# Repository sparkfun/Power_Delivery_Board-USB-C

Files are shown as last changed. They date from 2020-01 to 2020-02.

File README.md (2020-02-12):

SparkFun Power Delivery Board - USB-C
========================================

SparkFun Power Delivery Board - USB-C

[*SparkFun Power Delivery Board - USB-C (15801)*](https://www.sparkfun.com/products/15801)

<Basic description of the part.>

Repository Contents
-------------------

* **/Hardware** - Eagle design files (.brd, .sch)

Documentation
--------------
* **[Hookup Guide](https://learn.sparkfun.com/tutorials/power-delivery-board---usb-c-qwiic-hookup-guide)** - Basic hookup guide for the Power Delivery Board - USB-C.
* **[Arduino Library](https://github.com/sparkfun/SparkFun_STUSB4500_Arduino_Library)** - Arduino Library for use with the Power Delivery Board.
* **[SparkFun Fritzing repo](https://github.com/sparkfun/Fritzing_Parts)** - Fritzing diagrams for SparkFun products.

License Information
-------------------

This product is _**open source**_! 

Please review the LICENSE.md file for license information. 

If you have any questions or concerns on licensing, please contact technical support on our [SparkFun forums](https://forum.sparkfun.com/viewforum.php?f=152).

Distributed as-is; no warranty is given.

- Your friends at SparkFun.

_<COLLABORATION CREDIT>_

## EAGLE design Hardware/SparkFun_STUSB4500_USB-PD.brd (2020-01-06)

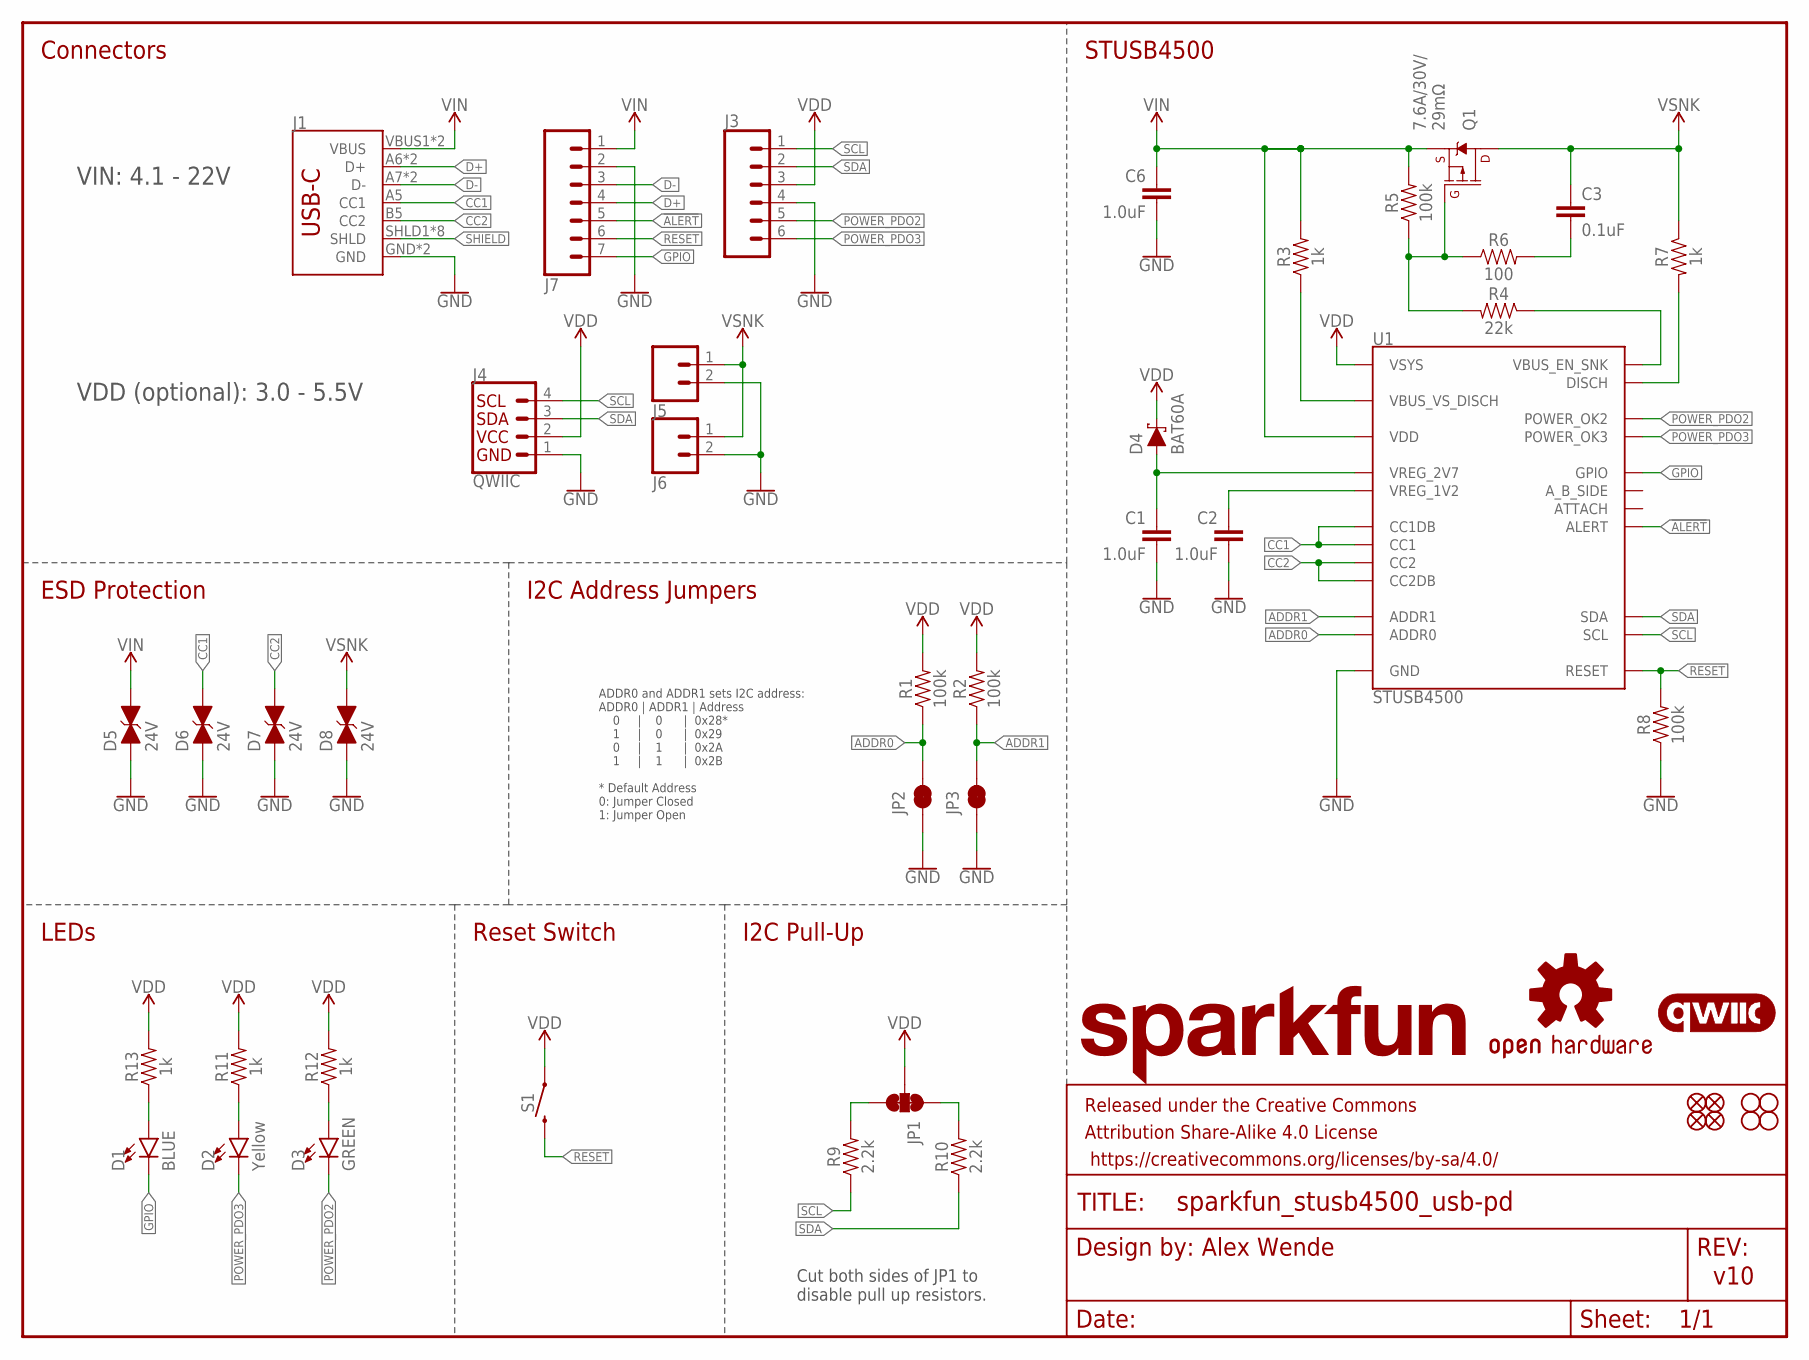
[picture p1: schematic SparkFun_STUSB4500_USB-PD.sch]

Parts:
C1, C2, C6: 1.0uF; 0603
C3: 0.1uF; 0603
D1: BLUE; LED-0603
D2: Yellow; LED-0603
D3: GREEN; LED-0603
D4: BAT60A; SOD-323
D5, D6, D7, D8: 24V; 0603
FD1, FD2, FD3, FD4: FIDUCIALUFIDUCIAL; FIDUCIAL-MICRO
FRAME1: FRAME-LETTER; CREATIVE_COMMONS
H1, H2, H3, H4: STAND-OFF
J1: USB_C2-LAYER; USB-C-16P
J3: CONN_06NO_SILK_NO_POP; 1X06_NO_SILK
J4: QWIIC; JST04_1MM_RA
J5: CONN_023.5MM; SCREWTERMINAL-3.5MM-2
J6: CONN_021X02_NO_SILK; 1X02_NO_SILK
J7: CONN_07NO_SILK; 1X07_NO_SILK
JP1: JUMPER-SMT_3_2-NC_TRACE_NO-SILK; SMT-JUMPER_3_2-NC_TRACE_NO-SILK
JP2, JP3: JUMPER-SMT_2_NC_TRACE_NO-SILK; SMT-JUMPER_2_NC_TRACE_NO-SILK
LOGO1: OSHW-LOGOS; OSHW-LOGO-S
LOGO2: SFE_LOGO_NAME.1_INCH; SFE_LOGO_NAME_.1
LOGO3: QWIIC_LOGO_5MM; QWIIC_5MM
Q1: 9A/30V/15mΩ; 8-POWERVDFN-3X3
R1, R2, R5, R8: 100k; 0603
R3, R7, R11, R12, R13: 1k; 0603
R4: 22k; 0603
R6: 100; 0603
R9, R10: 2.2k; 0603
S1: MOMENTARY-SWITCH-SPST-SMD-4.6X2.8MM; TACTILE_SWITCH_SMD_4.6X2.8MM
U1: STUSB4500; QFN-24

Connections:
1.2V: C2.1, U1.P$21 (VREG_1V2)
2.7V: C1.1, D4.A, U1.P$23 (VREG_2V7)
!ALERT: J7.5, U1.P$19 (ALERT)
ADDR0: JP2.2, R1.1, U1.P$12 (ADDR0)
ADDR1: JP3.2, R2.1, U1.P$13 (ADDR1)
CC1: D6.2 (C), J1.A5 (CC1), U1.P$1 (CC1DB), U1.P$2 (CC1)
CC2: D7.2 (C), J1.B5 (CC2), U1.P$4 (CC2), U1.P$5 (CC2DB)
D+: J1.A6 (D+), J1.B6 (D+), J7.4
D-: J1.A7 (D-), J1.B7 (D-), J7.3
DISCH: R7.2, U1.P$9 (DISCH)
EN_SNK: R4.1, U1.P$16 (VBUS_EN_SNK)
GND: C1.2, C2.2, C6.2, D5.1 (A), D6.1 (A), D7.1 (A), D8.1 (A), J1.GND, J1.GND2 (GND), J3.4, J4.1, J5.2, J6.2, J7.2, JP2.1, JP3.1, R8.1, U1.P$10 (GND), U1.P$25 (GND)
GPIO: D1.C, J7.7, U1.P$15 (GPIO)
unnamed: D2.A, R11.1
unnamed: D3.A, R12.1
unnamed: JP1.3, R9.2
unnamed: JP1.1, R10.2
unnamed: Q1.4 (G), R4.2, R5.1, R6.1
unnamed: C3.2, R6.2
unnamed: D1.A, R13.1
POWER_PDO2: D3.C, J3.5, U1.P$20 (POWER_OK2)
POWER_PDO3: D2.C, J3.6, U1.P$14 (POWER_OK3)
RESET: J7.6, R8.2, S1.3 (2), S1.4 (2), U1.P$6 (RESET)
SCL: J3.1, J4.4, R9.1, U1.P$7 (SCL)
SDA: J3.2, J4.3, R10.1, U1.P$8 (SDA)
SHIELD: J1.SHLD1 (SHLD), J1.SHLD2 (SHLD), J1.SHLD3 (SHLD), J1.SHLD4 (SHLD), J1.SHLD5 (SHLD), J1.SHLD6 (SHLD), J1.SHLD7 (SHLD), J1.SHLD8 (SHLD)
VBUS_VS_DISCH: R3.1, U1.P$18 (VBUS_VS_DISCH)
VDD: D4.C, J3.3, J4.2, JP1.2, R1.2, R2.2, R11.2, R12.2, R13.2, S1.1, S1.2 (1), U1.P$22 (VSYS)
VIN: C6.1, D5.2 (C), J1.VBUS1 (VBUS), J1.VBUS2 (VBUS), J7.1, Q1.1 (S), Q1.2 (S), Q1.3 (S), R3.2, R5.2, U1.P$24 (VDD)
VSNK: C3.1, D8.2 (C), J5.1, J6.1, Q1.5@1 (D), Q1.5@2 (D), Q1.5@3 (D), R7.1

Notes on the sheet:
ADDR0 and ADDR1 sets I2C address: ADDR0 | ADDR1 | Address 0 | 0 | 0x28* 1 | 0 | 0x29 0 | 1 | 0x2A 1 | 1 | 0x2B * Default Address 0: Jumper Closed 1: Jumper Open
Alex Wende
v10
STUSB4500
Connectors
I2C Pull-Up
LEDs
Reset Switch
I2C Address Jumpers
VIN: 4.1 - 22V
7.6A/30V/ 29mΩ
ESD Protection
VDD (optional): 3.0 - 5.5V
Cut both sides of JP1 to disable pull up resistors.

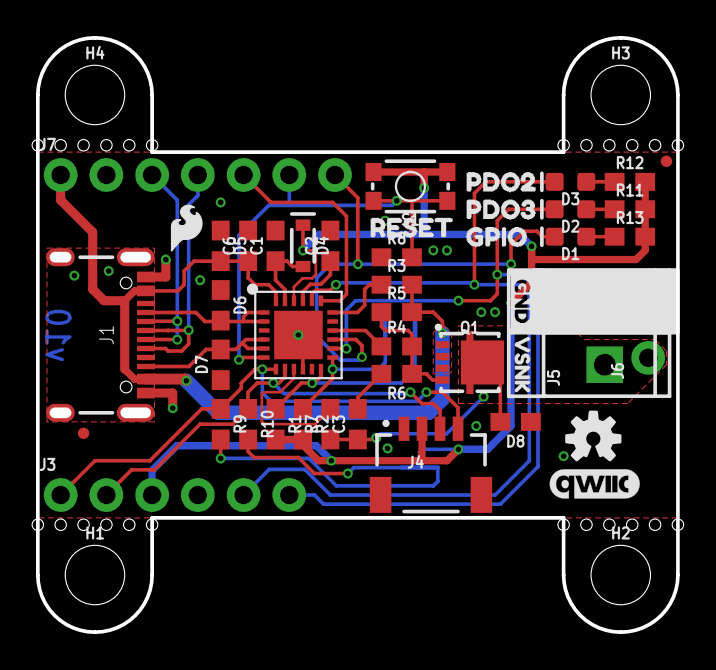
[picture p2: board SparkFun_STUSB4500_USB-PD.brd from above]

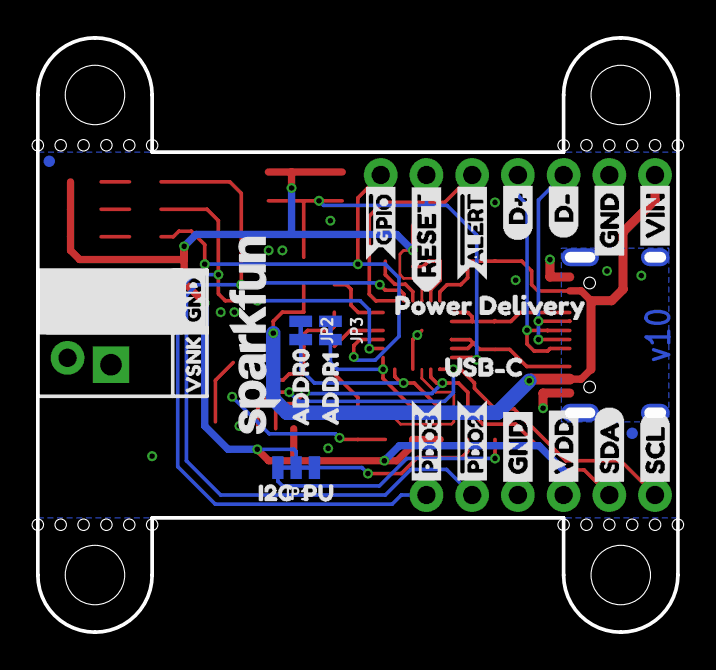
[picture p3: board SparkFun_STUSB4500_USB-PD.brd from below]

Board: 2 copper layers, 35.6 x 33.0 mm, 77 parts (27 on the bottom side), 30 nets.

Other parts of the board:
U$1: VDD2
U$2, U$11: GND6
U$3: SDA11
U$4: SCL12
U$5: #GPIO0
U$7: D#8
U$8: D#7
U$9: USB#C1
U$10: RESET10
U$12: VIN6
U$13: I2C2
U$14: PU3
U$15: ADDR00
U$16: ADDR11
U$17: RESET7
U$18: GPIO1
U$19: PDO24
U$20: PDO35
U$21, U$24: VSNK1
U$22, U$23: GND0
U$25: SFE_LOGO_FLAME_.1
U$26: #ALERT0
U$27: _POWER_DELIVERY2
U$29: #PDO20
U$30: #PDO31

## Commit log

2019-11-13 v02
    -Added ESD protection diodes to VIN,VSNK, CC1, CC2
    -Removed 3.3V LDO and replaced with the internal 2.7V regulated output of the STUSB4500.
    -Added reverse current protection to the 2.7V regulator when VDD > 2.7V
    [SparkFun_STUSB4500_USB-PD.brd, SparkFun_STUSB4500_USB-PD.sch]
2019-11-27 v20
    - Updated Labels
    - Connected VSYS to VDD
    - Replaced Power LED with GPIO LED
    [SparkFun_STUSB4500_USB-PD.brd, SparkFun_STUSB4500_USB-PD.sch]
2019-12-02 v10 Update
    - Updated STUSB4500 center pad paste
    - Updated all text to vector
    - Updated SCH to v10
    - Added text about jumpers
    [SparkFun_STUSB4500_USB-PD.brd, SparkFun_STUSB4500_USB-PD.sch]
2019-12-02 Update SparkFun_STUSB4500_USB-PD.brd
    Updated buzzard labels for PDO2 and PDO3
    [SparkFun_STUSB4500_USB-PD.brd]
2020-01-06 v10 Update
    Replaced GPIO buzzard label with active low indicator
    [SparkFun_STUSB4500_USB-PD.brd]

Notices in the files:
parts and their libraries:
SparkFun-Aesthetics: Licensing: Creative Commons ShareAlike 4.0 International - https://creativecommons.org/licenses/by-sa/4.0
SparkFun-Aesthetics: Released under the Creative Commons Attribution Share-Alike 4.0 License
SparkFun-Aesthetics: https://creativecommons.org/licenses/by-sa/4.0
